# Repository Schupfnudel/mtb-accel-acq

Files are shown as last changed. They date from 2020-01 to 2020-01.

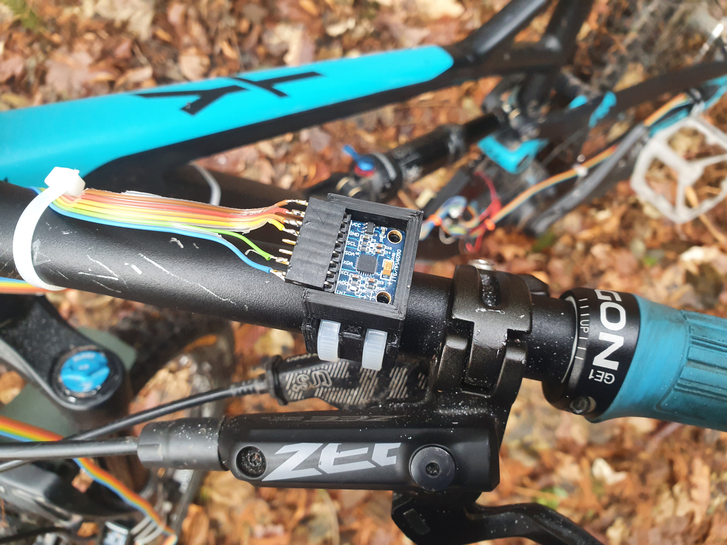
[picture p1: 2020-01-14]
pics/20200114_104616.jpg

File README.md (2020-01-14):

# mtb-accel-acq
Reading acceleration data from 3 MEMS accelerometers and saving them to SPI SD card, used to analyse behavior of MTB forks and shocks

Hardware:

Adafruit Itsybitsy M4 Express MCU

SPI microSD Reader

MPU6050 Accelerometers



The accelerometers are mounted on the handlebar, the fork and the left chainstay respectively. This is so I can differentiate between the forces from the front or back wheel, thus isolating the influence of the fork or the shock settings. The mounts are 3D printed from PLA. This is a relatively stiff material compared to other plastics I can 3d print, actually the best I can do. The breakout boards are fastened in the mounts with CA glue, that is also relatively stiff and should be fine. Screws do not work with my specific breakout boards because there are some passives mounted way too close to the screwholes... maybe try some other boards so you can screw and glue them in to avoid resonant oscillations of the pcb. Just dont use double sided tape or something similarly soft ;)
Ideally the mounts would be fastened to the bike with more screws or welds, but I like my bike without any holes in the frame, so the best I can do again is zipties. Not ideal for the chainstay, probably fine for the other two accelerometers. The holder for the batteries, MCU and SD card reader is not really critical, I quickly whipped up a holder to screw to the bottlecage. I dont inted to keep this setup on my bike for a long time, so I did not bother with waterproofing, everything is easily accessible.
For power I just use 4 AA batteries in a holder with a switch. The M4 board has an integrated LDO that can supply the accelerometers and SD card easily.

TODO:
- the SD reader permanently blocks SPI bus, CS does nothing. So I had to use the accelerometers with (slower) I2C. The maximum ODR of the MPU6050 is 1000Hz, so speed is not super critical, but I will try and find a better SD card reader.
- the SD card is not fast enough to write data in real time, big SPI flash would be better. For the moment I used onboard RAM of the M4 to buffer data for 5 seconds and then stop reading to save to SD card. There are 2MB SPI flash on the board too, but thats still not enough to buffer a full run and reading from the flash to SD card would take even longer, so I went with shorter bursts of data.
- 1kHz ODR and +-16g range are just guesses, after some tests slower ODR might enable real time data acquisition or smaller ranges might provide higher resolution
- actual data evaluation, probably in matlab when it gets warm enough for damping circuits to work properly

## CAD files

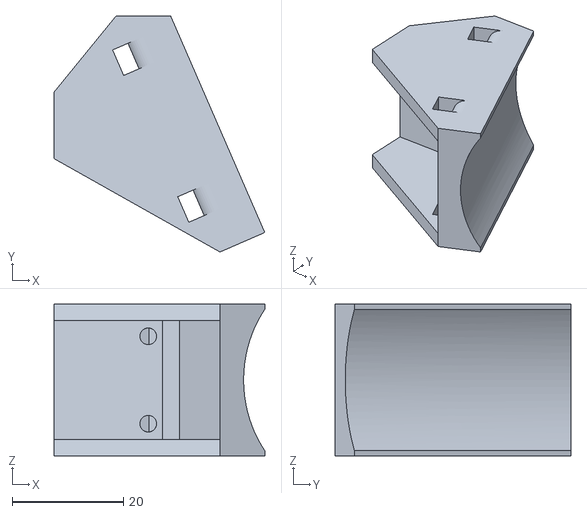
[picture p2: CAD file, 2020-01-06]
3Dmodels/Accel2_fork.stl
37.8 x 42.4 x 27.3

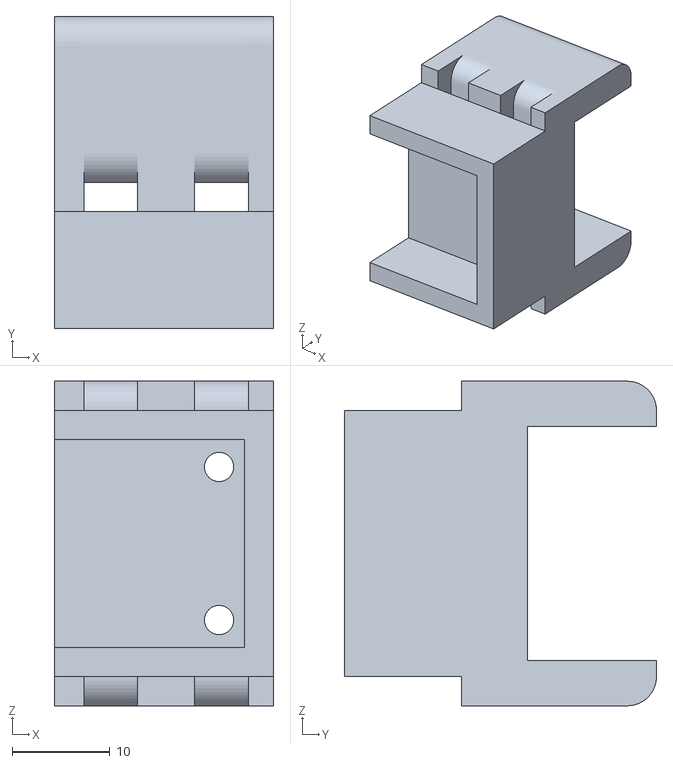
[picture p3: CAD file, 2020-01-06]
3Dmodels/Accel2_chainstay.stl
22.5 x 32.0 x 33.3

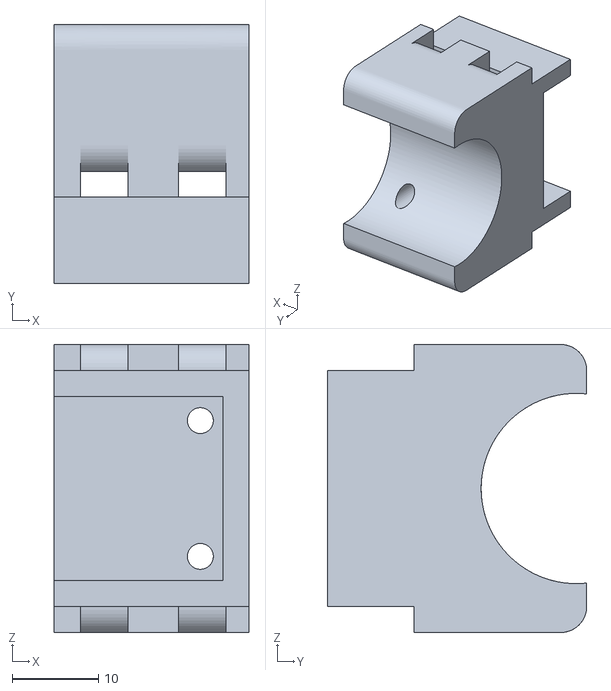
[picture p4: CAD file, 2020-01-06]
3Dmodels/Accel2_handlebar.stl
22.5 x 30.0 x 33.3

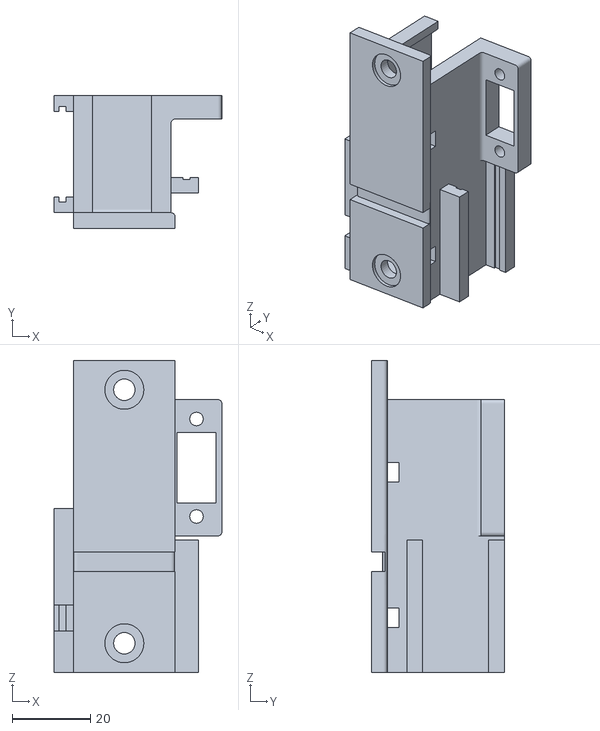
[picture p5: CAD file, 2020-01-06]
3Dmodels/Battery+sd+mcu v1.stl
43.0 x 34.0 x 80.0

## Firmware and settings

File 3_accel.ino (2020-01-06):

#include <Wire.h>
#include <SPI.h>
#include <SD.h>

const int chipSelect = A5; //CS für Sd Kartenleser eh wirkungslos
const int accel_kettenstrebe = 9;
const int accel_lenker = 10;
const int accel_rahmen = 11;
const int n_messwerte = 6000;
const int MPU_addr = 0x69; //MPUs have two different adresses available, to use three via I2C I toggle between them by setting one AD0 pin at a time HIGH and then reading
int16_t daten [n_messwerte][3][3];  // 3Darray for data, 1. number of buffered values, 2. three axes, 3. three sensors
unsigned long zeit [n_messwerte];   //timestamp, needed to calculate freq and ftt later on

void setup() {
  pinMode(LED_BUILTIN, OUTPUT);
  pinMode(accel_kettenstrebe, OUTPUT);
  pinMode(accel_lenker, OUTPUT);
  pinMode(accel_rahmen, OUTPUT);

  Wire.begin();
  Wire.setClock(400000);


  for (int m = 0; m < 3; m++) { //initialising all 3 MPUs
    if (m == 0) {
      digitalWrite(accel_kettenstrebe, HIGH);
      digitalWrite(accel_lenker, LOW);
      digitalWrite(accel_rahmen, LOW);
    }
    else if (m == 1) {
      digitalWrite(accel_kettenstrebe, LOW);
      digitalWrite(accel_lenker, HIGH);
      digitalWrite(accel_rahmen, LOW);
    }
    else {
      digitalWrite(accel_kettenstrebe, LOW);
      digitalWrite(accel_lenker, LOW);
      digitalWrite(accel_rahmen, HIGH);
    }


    Wire.beginTransmission(MPU_addr);
    Wire.write(0x1C);  //Range register
    Wire.write(0x18);     // 00 = 2g, 01 = 4g, 10 = 8g, 11 = 16g
    Wire.endTransmission(true);
    Wire.beginTransmission(MPU_addr);
    Wire.write(0x19);  // ODR register
    Wire.write(0);     // ODR = 8kHz/wert
    Wire.endTransmission(true);
    Wire.beginTransmission(MPU_addr);
    Wire.write(0x6B);  // PWR register
    Wire.write(0);     // wake up MPU6050
    Wire.endTransmission(true);
  }



  if (!SD.begin(chipSelect)) { //test if sd card present
    while (1);
    {
      digitalWrite(LED_BUILTIN, HIGH);
      delay(1000);
      digitalWrite(LED_BUILTIN, LOW);
      delay(1000);
    }
  }



}




void loop() {


  for (int i = 0; i < n_messwerte; i++) {

    for (int k = 0; k < 3; k++) {  //looping thru 3 MPUs to acq data, switching takes about 0,1ms, should be fine
      switch (k) {
        case 0:
          digitalWrite(accel_kettenstrebe, HIGH);
          digitalWrite(accel_lenker, LOW);
          digitalWrite(accel_rahmen, LOW);
          break;
        case 1:
          digitalWrite(accel_kettenstrebe, LOW);
          digitalWrite(accel_lenker, HIGH);
          digitalWrite(accel_rahmen, LOW);
          break;
        case 2:
          digitalWrite(accel_kettenstrebe, LOW);
          digitalWrite(accel_lenker, LOW);
          digitalWrite(accel_rahmen, HIGH);
          break;
        default:
          break;
      }
      Wire.beginTransmission(MPU_addr);
      Wire.write(0x3B);  // starting with register 0x3B (ACCEL_XOUT_H)
      Wire.endTransmission(false);
      Wire.requestFrom(MPU_addr, 6, true); // request a total of 6 registers
      zeit[i] = micros();
      daten[i][0][k] = Wire.read() << 8 | Wire.read(); // 0x3B (ACCEL_XOUT_H) & 0x3C (ACCEL_XOUT_L)
      daten[i][1][k] = Wire.read() << 8 | Wire.read(); // 0x3D (ACCEL_YOUT_H) & 0x3E (ACCEL_YOUT_L)
      daten[i][2][k] = Wire.read() << 8 | Wire.read(); // 0x3F (ACCEL_ZOUT_H) & 0x40 (ACCEL_ZOUT_L)
      Wire.endTransmission(true);

    }
  }

  File data = SD.open("accel.txt", FILE_WRITE); //save data to SD when RAM buffer is full

  for (int j = 0; j < n_messwerte; j++) { //format of csv for matlab extraction: timestamp, sensor1x, sensor1y, sensor1z, sensor2x ..... 
    data.print(zeit[j], DEC);
    data.write(", ");
    for (int l = 0; l < 3; l++) {
      data.print(daten[j][0][l], DEC);
      data.write(", ");
      data.print(daten[j][1][l], DEC);
      data.write(", ");
      data.print(daten[j][2][l], DEC);
      data.write(", ");
    }
    data.println();
  }
  data.flush();
}
